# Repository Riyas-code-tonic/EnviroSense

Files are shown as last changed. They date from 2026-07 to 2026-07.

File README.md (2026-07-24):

<div align="center">



# 🌳 𝓔𝓷𝓿𝓲𝓻𝓸𝑺𝒆𝒏𝒔𝒆

### Smart IoT Weather & Air Quality Monitoring System

*Turning real-time environmental data into meaningful insights.*

<br>







</div>

# 🌿 Overview

**EnviroSense** is a smart IoT platform that transforms environmental sensing into an interactive monitoring experience. Built around the ESP32 and the BME680 environmental sensor, the system continuously measures temperature, humidity, atmospheric pressure, and air quality before securely transmitting the data to the cloud.

Rather than limiting sensor readings to a serial monitor, EnviroSense combines cloud connectivity, a responsive web dashboard, local OLED visualization, intelligent email alerts, and power-efficient firmware to create a complete end-to-end monitoring solution. The project demonstrates how embedded systems, cloud communication, and modern web technologies can seamlessly work together to make environmental information accessible from anywhere.

---

# 🌐 Live Dashboard

Experience the deployed dashboard here:

### **https://enviro-sense-delta.vercel.app**

> *Live readings are available whenever the ESP32 device is connected and publishing data.*

---

## 📑 Table of Contents

- [Overview](#-overview)
- [Live Dashboard](#-live-dashboard)
- [About the Project](#-about-the-project)
- [Key Features](#-key-features)
- [How EnviroSense Works](#-how-envirosense-works)
- [Technologies Used](#-technologies-used)
- [Hardware](#-hardware)
- [PCB Design](#-pcb-design)
- [Challenges](#-challenges)
- [What We Learned](#-what-we-learned)
- [Future Scope](#-future-scope)
- [Contributors](#-contributors)

---

# 📖 About the Project

Environmental conditions constantly change, yet understanding those changes often requires specialised equipment or complex monitoring systems. EnviroSense was developed to bridge that gap by providing a compact, affordable, and intelligent platform capable of collecting, transmitting, and visualising environmental data in real time.

At its core, the ESP32 communicates with the BME680 sensor to measure temperature, humidity, atmospheric pressure, and gas resistance. The collected readings are published to Adafruit IO using the MQTT protocol, allowing them to be securely accessed through a custom-built web dashboard from virtually anywhere.

To make the system practical beyond simple monitoring, EnviroSense also incorporates an OLED display that provides live sensor readings directly on the device, enabling users nearby to instantly view environmental conditions without opening the dashboard. An integrated email alert system further enhances usability by automatically notifying users whenever predefined environmental thresholds are exceeded, ensuring that important changes never go unnoticed.

Together, these components transform EnviroSense from a simple sensor project into a complete IoT monitoring solution that combines embedded systems, cloud services, and web technologies into one cohesive platform.

---

## ⚡ Key Features

- Real-time environmental monitoring (Temperature, Humidity, Pressure & Air Quality)
- MQTT-based cloud communication
- Adafruit IO cloud integration
- Interactive web dashboard
- Automated email alert system
- Power optimization using Deep Sleep
- OLED display for local monitoring
- Responsive interface for desktop and mobile
- Secure cloud-based data visualization

---

# 🧠 How EnviroSense Works

EnviroSense follows a complete IoT workflow where sensing, communication, visualization, and notification work together to provide continuous environmental monitoring.

The BME680 sensor periodically measures temperature, humidity, atmospheric pressure, and gas resistance. These readings are collected by the ESP32, where they are processed, formatted, and prepared for transmission. Once connected to Wi-Fi, the ESP32 publishes the latest environmental data to Adafruit IO using the lightweight MQTT protocol, making the information available over the internet in real time.

The custom-built web dashboard retrieves these values from the cloud and updates the visual interface automatically. Interactive gauges and graphs allow users to monitor changing environmental conditions from any device without requiring direct access to the hardware.

For users who are physically near the device, the integrated OLED display provides an immediate view of the latest sensor readings. This enables quick local monitoring even when internet access or the dashboard is unavailable, making the system useful in both remote and on-site environments.

EnviroSense also includes an automated email notification system designed to improve responsiveness. Whenever monitored parameters exceed predefined threshold values, the system automatically triggers an email alert, allowing users to take timely action without continuously checking the dashboard. This makes the platform suitable for applications where immediate awareness of environmental changes is important.

To improve efficiency and reduce unnecessary power consumption, the firmware incorporates power optimization techniques such as **Deep Sleep mode**. Instead of remaining active continuously, the ESP32 periodically wakes up, collects sensor readings, transmits the data to the cloud, updates the OLED display, checks alert conditions, and then returns to a low-power sleep state. This significantly reduces energy usage and extends battery life, making EnviroSense better suited for long-term deployments in remote or battery-powered environments.

The overall workflow can be summarized as follows:

```
        BME680 Environmental Sensor
                   │
                   ▼
        ESP32 Microcontroller
                   │
      Reads & Processes Sensor Data
                   │
                   ▼
           Wi-Fi + MQTT Protocol
                   │
                   ▼
            Adafruit IO Cloud
                   │
         ┌─────────┴──────────┐
         ▼                    ▼
  Web Dashboard         Email Alerts
         ▲
         │
 Local OLED Display
```

By combining cloud communication, local visualization, intelligent notifications, and energy-efficient firmware, EnviroSense delivers a reliable environmental monitoring solution that remains practical for both everyday use and long-term IoT deployments.

---

# 🛠 Technologies Used

### Hardware

- ESP32 Development Board
- BME680 Environmental Sensor
- OLED Display

### Software & Cloud

- Arduino IDE
- HTML
- CSS
- JavaScript
- MQTT
- Adafruit IO
- Vercel

---

# 🔌 Hardware

The hardware combines the ESP32 with the BME680 environmental sensor to continuously monitor atmospheric conditions. An integrated OLED display allows nearby users to view live sensor readings directly from the device, while the ESP32 manages wireless communication, cloud connectivity, email notifications, and power-efficient operation within a compact embedded system.

---

# 📐 PCB Design

To improve reliability and move beyond a breadboard prototype, a dedicated PCB was designed for the system. The custom PCB provides cleaner connections, better durability, and a more compact implementation, making the overall design easier to assemble, maintain, and deploy.

---

# 🚧 Challenges

Developing EnviroSense involved much more than interfacing a sensor. Integrating reliable cloud communication, designing an intuitive dashboard, implementing automated notifications, optimizing power consumption, and ensuring smooth interaction between hardware and software required continuous testing, debugging, and refinement. Overcoming these challenges helped transform the project into a stable and practical IoT solution.

---

# 🎓 What We Learned

EnviroSense provided valuable experience in designing complete IoT systems that combine embedded hardware with cloud-based applications. Throughout the project, we strengthened our understanding of sensor interfacing, MQTT communication, responsive web development, cloud deployment, PCB design, power optimization, debugging, and collaborative software development while learning how independently developed components can be integrated into a single, scalable solution.

---

# 🚀 Future Scope

Although EnviroSense already provides a comprehensive environmental monitoring solution, several enhancements can further extend its capabilities:

- Machine learning-based environmental prediction
- Mobile application support
- Historical data analytics
- Multi-device monitoring
- User authentication
- Additional environmental sensors
- Customizable alert thresholds

---

# 👨‍💻 Contributors

- **Rajnarayan Hazra**
- **Riya Pailwan**
- **Harsh Patange**

---

# ⭐ Support

If you found this project interesting, consider giving the repository a **Star ⭐**. Your support motivates us to continue improving EnviroSense and building more innovative open-source projects.

---

<div align="center">

Made with ❤️ using ESP32, IoT, and Web Technologies.

</div>

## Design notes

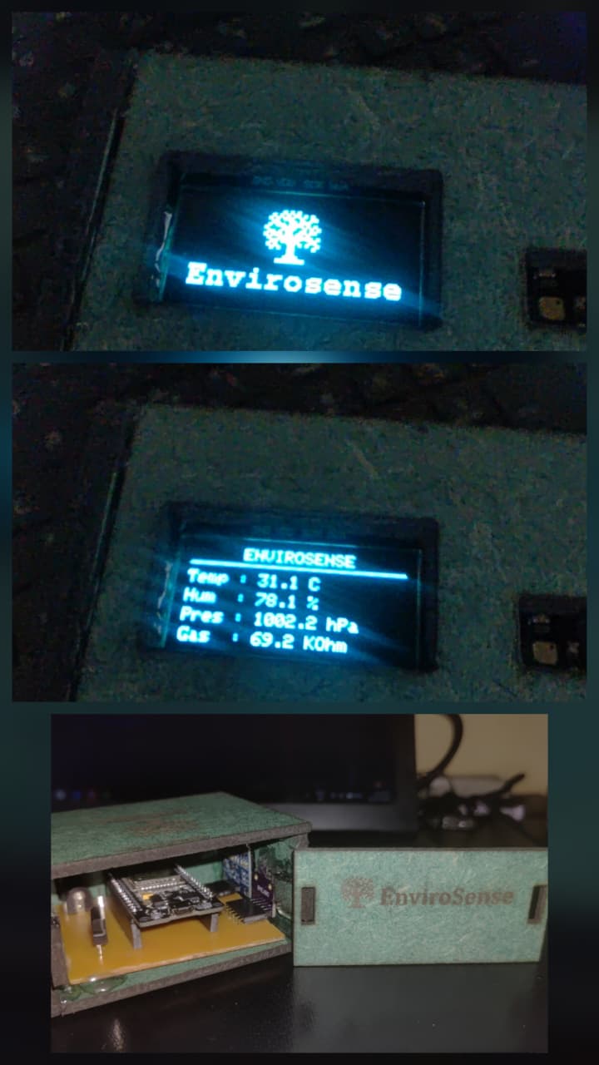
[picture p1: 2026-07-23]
Images/Hardware Case/Display.jpg

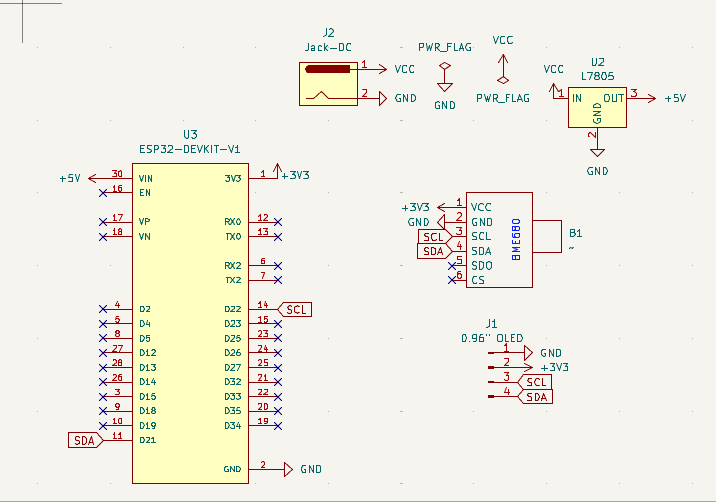
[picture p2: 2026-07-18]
Images/PCB/schematics.png

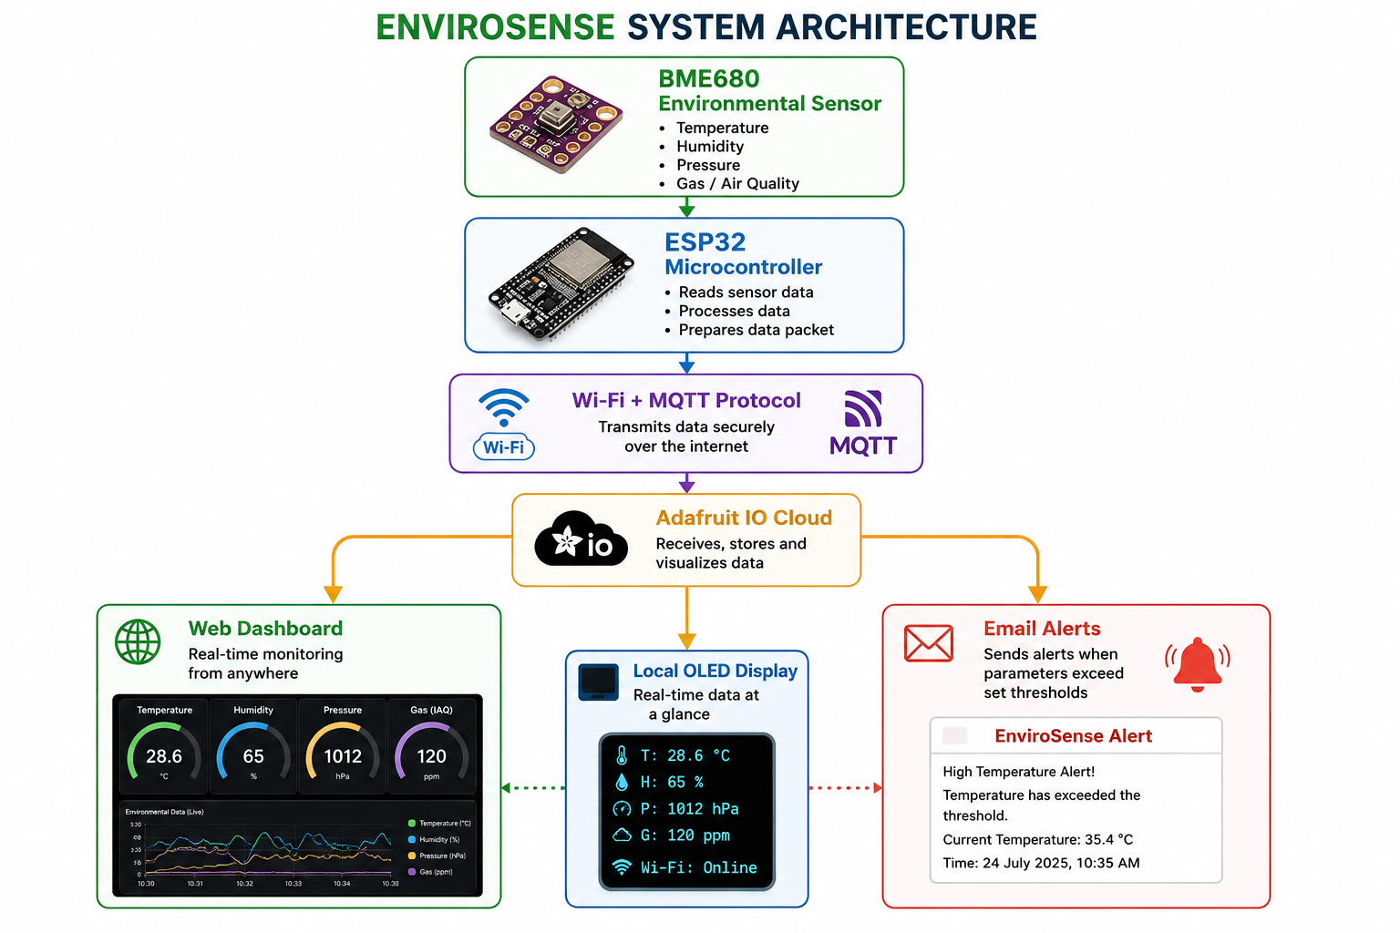
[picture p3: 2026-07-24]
Images/Envirosense Architecture.png

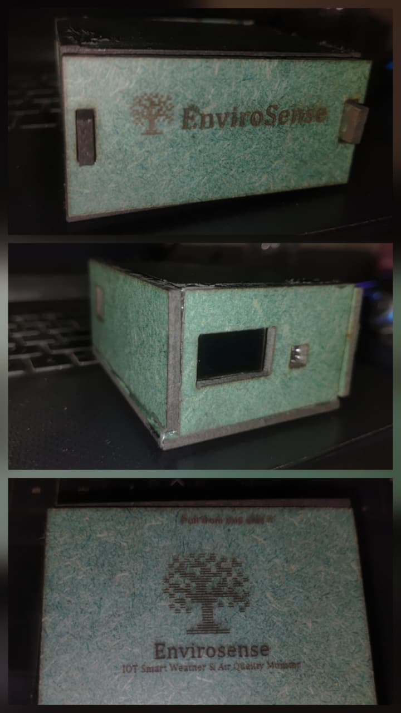
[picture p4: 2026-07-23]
Images/Hardware Case/Hardware Case.jpeg

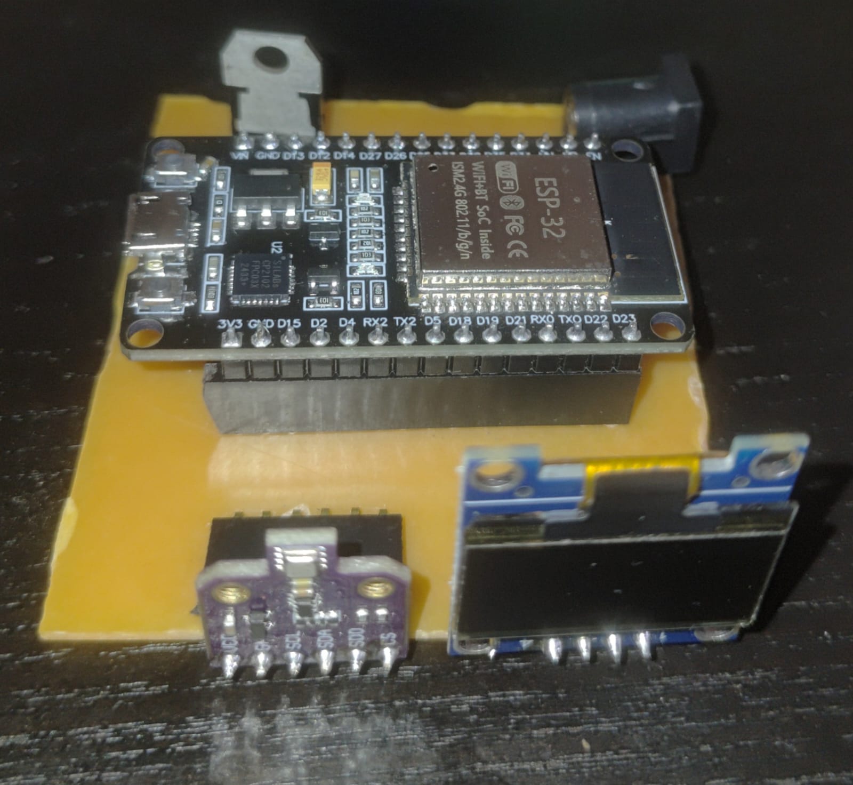
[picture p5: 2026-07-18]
Hardware/FINALPCB.jpeg

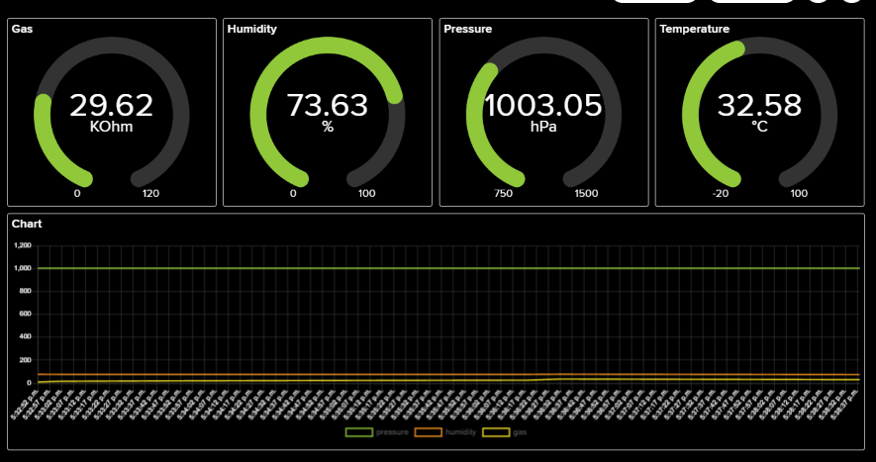
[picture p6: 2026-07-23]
Images/MQTT Server/Dashboard 1.png

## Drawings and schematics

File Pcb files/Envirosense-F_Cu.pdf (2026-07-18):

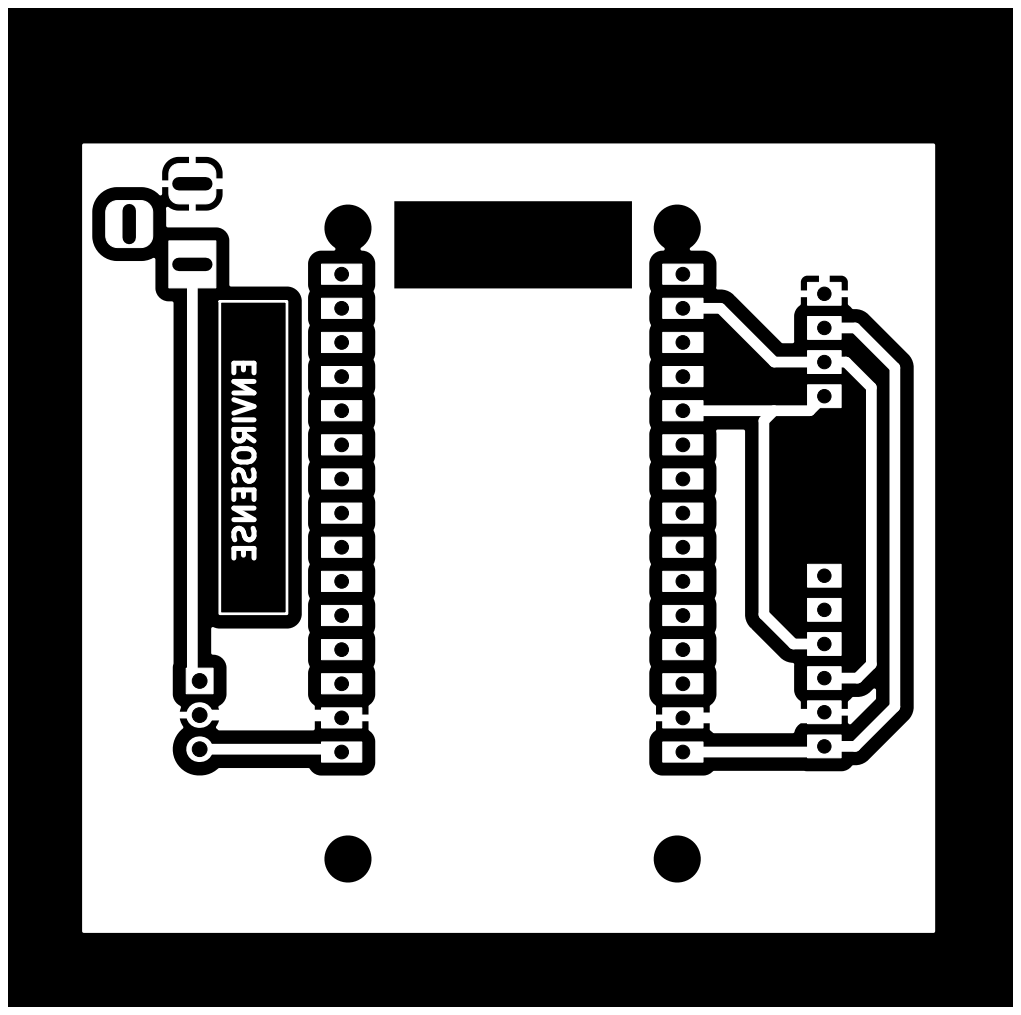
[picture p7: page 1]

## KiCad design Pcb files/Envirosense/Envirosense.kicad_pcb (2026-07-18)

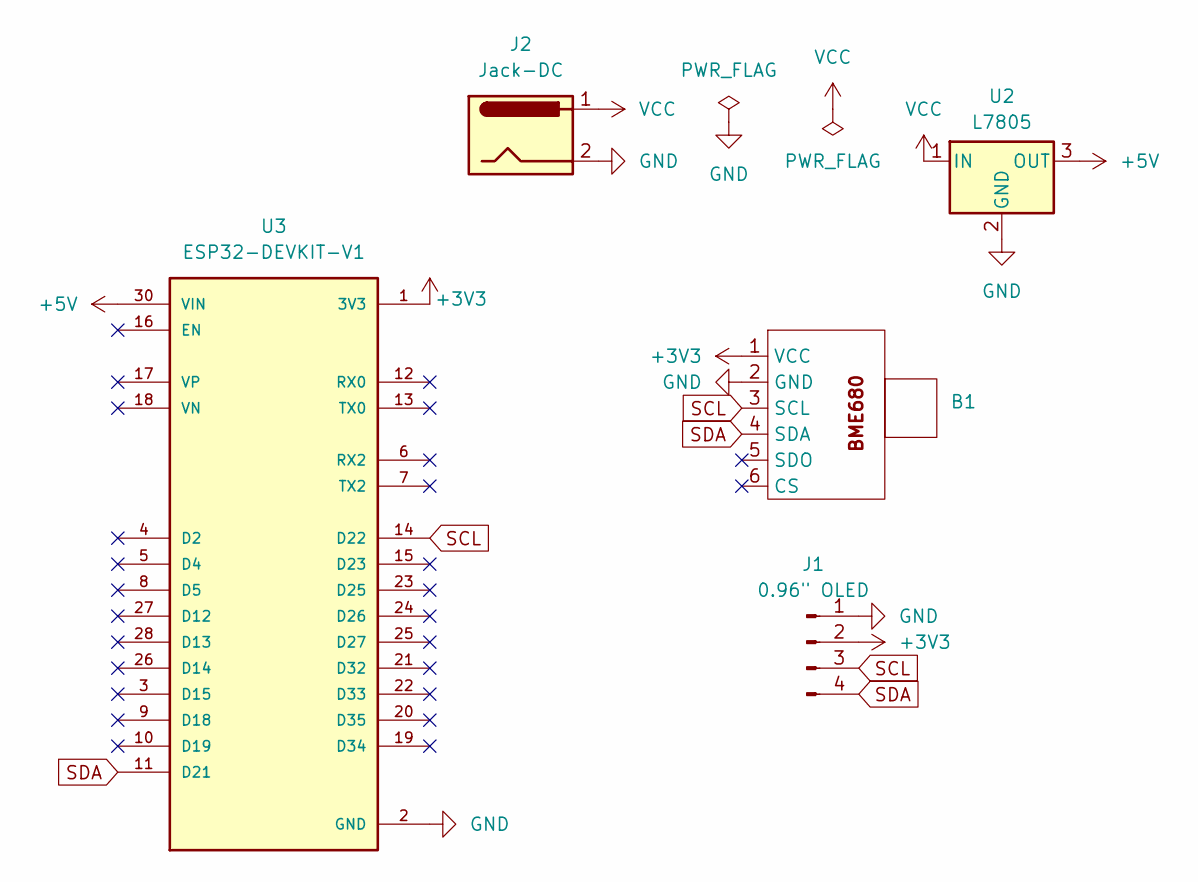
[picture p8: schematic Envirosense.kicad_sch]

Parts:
B1: PinHeader_1x06_P2.54mm_Vertical
J1: 0.96" OLED; PinHeader_1x04_P2.54mm_Vertical
J2: Jack-DC; BarrelJack_Horizontal
U2: L7805; TO-220-3_Vertical
U3: ESP32-DEVKIT-V1; MODULE_ESP32_DEVKIT_V1; PARTREV N/A

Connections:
+3V3: B1.1 (VCC), J1.2, U3.1 (3V3)
+5V: U2.3 (OUT), U3.30 (VIN)
GND: B1.2 (GND), J1.1, J2.2, U2.2 (GND), U3.2 (GND), U3.29 (GND)
SCL: B1.3 (SCL), J1.3, U3.14 (D22)
SDA: B1.4 (SDA), J1.4, U3.11 (D21)
VCC: J2.1, U2.1 (IN)

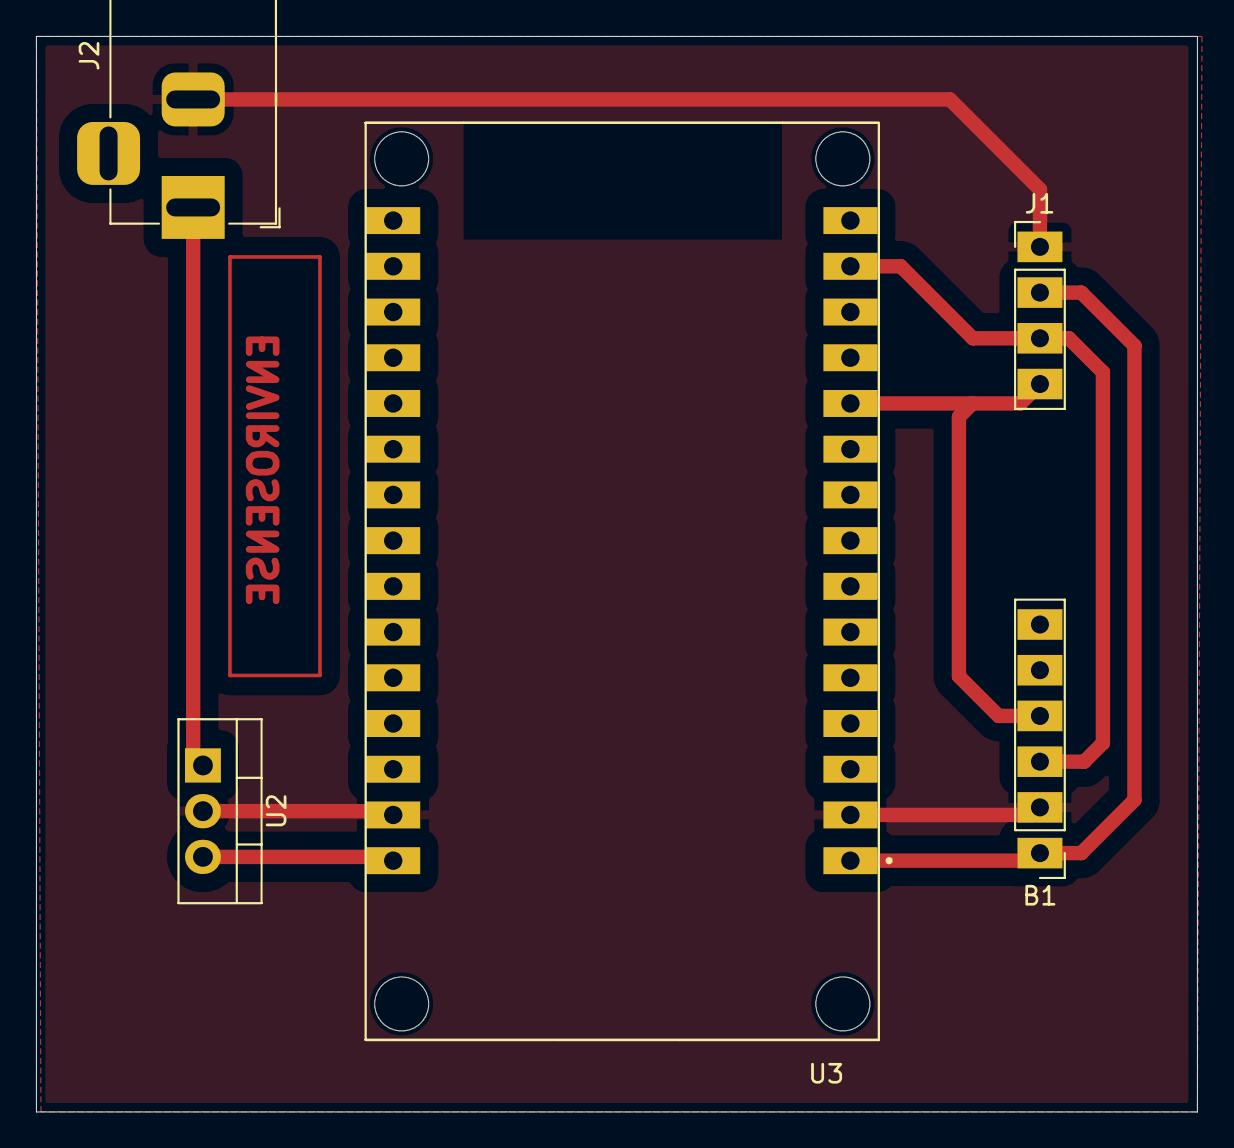
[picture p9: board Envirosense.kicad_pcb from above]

Board: 2 copper layers, 64.5 x 59.8 mm, 5 parts (0 on the bottom side), 6 nets.

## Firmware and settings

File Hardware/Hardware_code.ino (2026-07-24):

#include <WiFi.h>
#include "Adafruit_MQTT.h"
#include "Adafruit_MQTT_Client.h"
#include <Wire.h>
#include <Adafruit_GFX.h>
#include <Adafruit_SSD1306.h>
#include <Adafruit_Sensor.h>
#include <Adafruit_BME680.h>
#include <ESP_Mail_Client.h>
#include "S:\Arduino\libraries\Adafruit_GFX_Library\Fonts\FreeMonoBold9pt7b.h"

// ================================================================
// PERSISTENT RTC VARIABLES (Survive Deep Sleep)
// ================================================================
RTC_DATA_ATTR bool wasAboveLimit = false;
RTC_DATA_ATTR int minutesAboveLimit = 0;  // Counts consecutive high-temp cycles

// Email Alert Variable
const float TEMP_LIMIT = 35.0;
const int TriggerAlertinMins = 5; //After 5 minutes of continuous high temperature, send another email alert

//-------------------- I2C --------------------
#define SDA_PIN 21
#define SCL_PIN 22
#define SCREEN_WIDTH 128
#define SCREEN_HEIGHT 64

//-------------------- Deep Sleep --------------------
#define uS_TO_S_FACTOR 1000000ULL
#define TIME_TO_SLEEP 60

//-------------------- WiFi --------------------
#define WLAN_SSID "Raj_4g"
#define WLAN_PASS "....."

//-------------------- Adafruit IO --------------------
#define AIO_SERVER "io.adafruit.com"
#define AIO_SERVERPORT 1883
#define AIO_USERNAME "Rajnarayan"
#define AIO_KEY ".........."

//===========================
// Gmail Credentials
//===========================
#define SMTP_HOST "smtp.gmail.com"
#define SMTP_PORT 465

#define AUTHOR_EMAIL "abcd@gmail.com"
#define AUTHOR_PASSWORD "......"

#define RECIPIENT_EMAIL1 "2024.rajnarayan.hazra@ves.ac.in"
// #define RECIPIENT_EMAIL2 "2024.riya.pailwan@ves.ac.in"
// #define RECIPIENT_EMAIL3 "asawari.dudwadkar@ves.ac.in"

//===========================

//-------------------- Objects --------------------

Adafruit_BME680 bme;
Adafruit_SSD1306 display(SCREEN_WIDTH, SCREEN_HEIGHT, &Wire, -1);

WiFiClient client;

SMTPSession smtp;
Session_Config config;
SMTP_Message message;

Adafruit_MQTT_Client mqtt(
  &client,
  AIO_SERVER,
  AIO_SERVERPORT,
  AIO_USERNAME,
  AIO_KEY);

// Feeds
Adafruit_MQTT_Publish tempFeed(&mqtt, AIO_USERNAME "/feeds/temperature");
Adafruit_MQTT_Publish humFeed(&mqtt, AIO_USERNAME "/feeds/humidity");
Adafruit_MQTT_Publish pressFeed(&mqtt, AIO_USERNAME "/feeds/pressure");
Adafruit_MQTT_Publish gasFeed(&mqtt, AIO_USERNAME "/feeds/gas");

//------------------------------------------------
// Callback
//------------------------------------------------
void smtpCallback(SMTP_Status status) {
  Serial.println(status.info());

  if (status.success()) {
    Serial.println("Email sent successfully!");
  } else {
    Serial.println("Failed to send email.");
  }
}

//------------------------------------------------
// Send Email
//------------------------------------------------
void sendEmail(String ledState) {
  message.sender.name = "EnviroSense";
  message.sender.email = AUTHOR_EMAIL;

  message.subject = "The threshold has been exceeded";

  message.addRecipient("Receiver", RECIPIENT_EMAIL1);
  // message.addRecipient("Receiver", RECIPIENT_EMAIL2);
  // message.addRecipient("Receiver", RECIPIENT_EMAIL3);

  String body;

  body += "Hello,\n\n";
  body += "The temperature has 🚨exceeded the recommended threshold.\n\n";
  body += "Current Temperature: ";
  body += ledState;
  body += " °C 🌡️\n\n";
  body += "This is an automated email.\n";
  body += "\nRegards,\nEnviroSense🌳";

  message.text.content = body.c_str();
  message.text.charSet = "utf-8";
  message.text.transfer_encoding = Content_Transfer_Encoding::enc_7bit;

  smtp.callback(smtpCallback);

  if (!smtp.connect(&config)) {
    Serial.println("SMTP Connection Failed");
    return;
  }

  if (!MailClient.sendMail(&smtp, &message)) {
    Serial.println("Error Sending Email");
    Serial.println(smtp.errorReason());
  }

  message.clearRecipients();
}

//---------------------------------------
//Deep Sleep
//---------------------------------------

void goToSleep() {

  display.clearDisplay();
  display.setTextSize(1);
  display.setTextColor(SSD1306_WHITE);

  display.setCursor(20, 32);
  display.println("Deep Sleep Mode");
  Serial.println("Going to sleep...");
  display.display();
  delay(2000);
  display.clearDisplay();
  display.display();
  Serial.flush();

  esp_sleep_enable_timer_wakeup(TIME_TO_SLEEP * uS_TO_S_FACTOR);
  esp_deep_sleep_start();
}

//---------------------------------------
//Wifi Connect
//---------------------------------------
void connectWiFi() {

  if (WiFi.status() == WL_CONNECTED)
    return;

  Serial.print("Connecting WiFi");

  WiFi.begin(WLAN_SSID, WLAN_PASS);

  while (WiFi.status() != WL_CONNECTED) {
    delay(500);
    Serial.print(".");
  }

  Serial.println("\nWiFi Connected");
}


//---------------------------------------
//MQTT Connect
//---------------------------------------
void connectMQTT() {

  while (!mqtt.connected()) {

    Serial.print("Connecting to Adafruit IO... ");

    int8_t ret = mqtt.connect();

    if (ret == 0) {
      Serial.println("Connected!");
    } else {
      Serial.println(mqtt.connectErrorString(ret));
      mqtt.disconnect();
      delay(5000);
    }
  }
}

//-------Connect Email------------------------
void connectEmail() {
  // SMTP Configuration
  config.server.host_name = SMTP_HOST;
  config.server.port = SMTP_PORT;

  config.login.email = AUTHOR_EMAIL;
  config.login.password = AUTHOR_PASSWORD;

  config.login.user_domain = "";
}
//-------Logo Splash Screen------------
void logo() {

  static const unsigned char PROGMEM image_tree_bits[] = { 0x00, 0x33, 0x30, 0x00, 0x00, 0x33, 0x30, 0x00, 0x0c,
                                                           0xcc, 0xf3, 0x30, 0x0c, 0xcc, 0xf3, 0x30, 0x33, 0x3f, 0x0c, 0x3c, 0x33, 0x3f, 0x0c, 0x3c, 0x0f, 0x03, 0xcf, 0xc0, 0x0f,
                                                           0x03, 0xcf, 0xc0, 0x33, 0xf3, 0xfc, 0xcc, 0x33, 0xf3, 0xfc, 0xcc, 0xc0, 0x3f, 0xc3, 0x33, 0xc0, 0x3f, 0xc3, 0x33, 0x3c,
                                                           0xcf, 0x0f, 0x3c, 0x3c, 0xcf, 0x0f, 0x3c, 0xcf, 0xcf, 0x3c, 0xc0, 0xcf, 0xcf, 0x3c, 0xc0, 0x30, 0xff, 0xff, 0xf3, 0x30,
                                                           0xff, 0xff, 0xf3, 0x0f, 0x3f, 0xf0, 0x3c, 0x0f, 0x3f, 0xf0, 0x3c, 0x33, 0x03, 0xcc, 0xc3, 0x33, 0x03, 0xcc, 0xc3, 0x0c,
                                                           0xc3, 0xc0, 0x0c, 0x0c, 0xc3, 0xc0, 0x0c, 0x00, 0x03, 0xc0, 0x00, 0x00, 0x03, 0xc0, 0x00, 0x00, 0x03, 0xc0, 0x00, 0x00,
                                                           0x03, 0xc0, 0x00, 0x00, 0x0f, 0xf0, 0x00, 0x00, 0x0f, 0xf0, 0x00, 0x00, 0xff, 0xff, 0x00, 0x00, 0xff, 0xff, 0x00 };

  display.clearDisplay();
  // tree
  display.drawBitmap(45, 5, image_tree_bits, 32, 32, 1);
  // string 2
  display.setTextColor(1);
  display.setTextWrap(false);
  display.setFont(&FreeMonoBold9pt7b);
  display.setCursor(4, 52);
  display.print("Envirosense");
  display.display();
}
void checkAlert(float temperature) {
  //----------Email Alert Function-------------
  String strTemp = String(temperature, 2);
  // 2. THRESHOLD EVALUATION WITH 5-MINUTE RE-ALERT
  if (temperature > TEMP_LIMIT) {

    if (!wasAboveLimit) {
      // Initial spike above 30°C -> Send immediate email
      Serial.println("🚨 RISING EDGE: Temp crossed above 30°C! Sending alert...");
      sendEmail(strTemp);

      wasAboveLimit = true;
      minutesAboveLimit = 1;  // Start counter at 1 minute
    } else {
      // Temperature is STILL high on subsequent 1-minute wakeups
      minutesAboveLimit++;
      Serial.print("⚠️ Temp still high. Minute count: ");
      Serial.println(minutesAboveLimit);

      if (minutesAboveLimit >= TriggerAlertinMins) {
        // 5 minutes have passed -> Re-trigger email alert
        Serial.println("🚨 5-MINUTE REMINDER: Temp still above 30°C! Sending alert...");
        sendEmail(strTemp);

        minutesAboveLimit = 0;  // Reset counter for the next 5-minute cycle
      } else {
        // Waiting for the 5-minute mark to pass
        Serial.println("ℹ️ Temp still high — skipping duplicate email alert.");
      }
    }
  } else {
    // Temperature is NORMAL (<= 30°C)
    if (wasAboveLimit) {
      Serial.println("✅ RESET: Temp dropped below 30°C.");
    } else {
      Serial.println("✅ Temp normal.");
    }

    // Reset RTC flags
    wasAboveLimit = false;
    minutesAboveLimit = 0;
  }
}

void setup() {

  Serial.begin(115200);
  delay(500);

  Wire.begin(SDA_PIN, SCL_PIN);

  // OLED
  if (display.begin(SSD1306_SWITCHCAPVCC, 0x3C)) {
    display.clearDisplay();
    logo();
    delay(2000);

    // Reset to the regular font for the main sensor display
    display.setTextSize(1);
    display.setTextColor(SSD1306_WHITE);
    display.setFont();
  }

  // BME680
  if (!bme.begin()) {
    Serial.println("BME680 not found!");
    goToSleep();
  }

  //BME Sensor reading & Display-------------------------------------------
  bme.setTemperatureOversampling(BME680_OS_8X);
  bme.setHumidityOversampling(BME680_OS_2X);
  bme.setPressureOversampling(BME680_OS_4X);
  bme.setIIRFilterSize(BME680_FILTER_SIZE_3);
  bme.setGasHeater(320, 150);

  if (!bme.performReading()) {
    Serial.println("Sensor read failed");
    goToSleep();
  }

  float temperature = bme.temperature;
  float humidity = bme.humidity;
  float pressure = bme.pressure / 100.0;
  float gas = bme.gas_resistance / 1000.0;

  // OLED Display
  display.clearDisplay();
  display.setTextSize(1);
  display.setTextColor(SSD1306_WHITE);

  display.setCursor(32, 0);
  display.println("ENVIROSENSE");
  display.drawFastHLine(0, 10, 128, SSD1306_WHITE);

  display.setCursor(0, 16);
  display.printf("Temp : %.1f C", temperature);

  display.setCursor(0, 28);
  display.printf("Hum  : %.1f %%", humidity);

  display.setCursor(0, 40);
  display.printf("Pres : %.1f hPa", pressure);

  display.setCursor(0, 52);
  display.printf("Gas  : %.1f KOhm", gas);
  display.display();


  //-----------------------------------------------------------------------------

  // WiFi & MQTT
  connectWiFi();
  connectMQTT();

  mqtt.processPackets(100);
  mqtt.ping();

  // Publish to Adafruit IO
  tempFeed.publish(temperature);
  humFeed.publish(humidity);
  pressFeed.publish(pressure);
  gasFeed.publish(gas);

  Serial.println("Published to Adafruit IO");
  connectEmail();
  checkAlert(temperature);
  delay(3000);
  goToSleep();
}

void loop() {
}

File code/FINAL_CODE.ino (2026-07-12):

#include <WiFi.h>
#include <HTTPClient.h>
#include <Wire.h>

#include <Adafruit_GFX.h>
#include <Adafruit_SSD1306.h>

#include <Adafruit_Sensor.h>
#include <Adafruit_BME680.h>

#include <ArduinoJson.h>

#define SDA_PIN 21
#define SCL_PIN 22

#define SCREEN_WIDTH 128
#define SCREEN_HEIGHT 64

#define SEALEVELPRESSURE_HPA 1013.25

const char* ssid = "HELLO";
const char* password = "12345678";

// Replace with your Render URL
const char* serverURL = "https://envirosense-backend.onrender.com/sensor";

Adafruit_BME680 bme;
Adafruit_SSD1306 display(SCREEN_WIDTH, SCREEN_HEIGHT, &Wire, -1);

void connectWiFi()
{
    if (WiFi.status() == WL_CONNECTED)
        return;

    Serial.println("Connecting to WiFi...");

    WiFi.begin(ssid, password);

    while (WiFi.status() != WL_CONNECTED)
    {
        delay(500);
        Serial.print(".");
    }

    Serial.println();
    Serial.println("WiFi Connected");
    Serial.print("IP Address : ");
    Serial.println(WiFi.localIP());
}

void setup()
{
    Serial.begin(115200);

    Wire.begin(SDA_PIN, SCL_PIN);

    if (!display.begin(SSD1306_SWITCHCAPVCC, 0x3C))
    {
        Serial.println("OLED Failed");
        while (1);
    }

    display.clearDisplay();
    display.setTextSize(1);
    display.setTextColor(SSD1306_WHITE);

    if (!bme.begin())
    {
        Serial.println("BME680 Not Found");
        while (1);
    }

    bme.setTemperatureOversampling(BME680_OS_8X);
    bme.setHumidityOversampling(BME680_OS_2X);
    bme.setPressureOversampling(BME680_OS_4X);
    bme.setIIRFilterSize(BME680_FILTER_SIZE_3);
    bme.setGasHeater(320, 150);

    connectWiFi();

    Serial.println("-------------------------");
    Serial.println("EnviroSense Started");
    Serial.println("-------------------------");
}

void loop()
{
    connectWiFi();

    if (!bme.performReading())
    {
        Serial.println("Sensor Reading Failed");
        delay(2000);
        return;
    }

    float temperature = bme.temperature;
    float humidity = bme.humidity;
    float pressure = bme.pressure / 100.0;
    float gas = bme.gas_resistance / 1000.0;

    display.clearDisplay();
    display.setTextSize(1);
    display.setTextColor(SSD1306_WHITE);

    // Title
    display.setCursor(20, 0);
    display.println("ENVIROSENSE");

    // Horizontal line
    display.drawFastHLine(0, 10, 128, SSD1306_WHITE);

    // Temperature
    display.setCursor(0, 16);
    display.print("Temp: ");
    display.print(temperature, 1);
    display.print(" C");

    // Humidity
    display.setCursor(0, 28);
    display.print("Humid: ");
    display.print(humidity, 1);
    display.print(" %");

    // Pressure
    display.setCursor(0, 40);
    display.print("Pres: ");
    display.print(pressure, 1);
    display.print(" hPa");

    // Gas
    display.setCursor(0, 52);
    display.print("Gas: ");
    display.print(gas, 1);
    display.print(" KOhms");

    display.display();

    if (WiFi.status() == WL_CONNECTED)
    {
        HTTPClient http;

        http.begin(serverURL);

        http.addHeader("Content-Type", "application/json");

        StaticJsonDocument<256> doc;

        doc["temperature"] = temperature;
        doc["humidity"] = humidity;
        doc["pressure"] = pressure;
        doc["gas"] = gas;

        String json;

        serializeJson(doc, json);

        Serial.println("-------------------------");
        Serial.println("Sending Data...");
        Serial.println(json);

        int httpCode = http.POST(json);

        Serial.print("HTTP Response Code : ");
        Serial.println(httpCode);

        if (httpCode > 0)
        {
            Serial.println("Data Sent Successfully");
            Serial.println(http.getString());
        }
        else
        {
            Serial.println("Failed to Send Data");
        }

        http.end();
    }
    else
    {
        Serial.println("WiFi Disconnected");
    }

    delay(5000);
}

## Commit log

2026-06-27 Added Breadboard Circuit image
2026-06-27 Added the PCB layout and routing pdf
2026-07-18 WEEK 4
    [Envirosense.kicad_pcb]
2026-07-21 Week 5
    [Envirosense.kicad_sch, circuit diagram.kicad_pcb, circuit diagram.kicad_sch]
2026-07-24 Update project files
    [Envirosense.kicad_pcb, Envirosense.kicad_sch]
2026-07-24 Rename Pcb files/Envirosense/Envirosense-F_Cu.pdf to Pcb files/Envirosense-F_Cu.pdf
2026-07-24 Rename Pcb files/Envirosense-F_Cu.pdf to Pcb files/Envirosense/Envirosense-F_Cu.pdf
